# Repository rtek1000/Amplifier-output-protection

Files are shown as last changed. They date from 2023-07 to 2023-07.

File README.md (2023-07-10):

# Amplifier-output-protection
Thermal protection for class AB amplifier output transistors

- Most class AB amplifiers built with NPN and PNP transistors are very poor in protection.
- - Some designs put a simple current limiter, but this does not guarantee the thermal protection of the transistor.
- - Some amplifier manufacturers use a fixed mechanical thermostat of about 100°C against the heatsink.

The partial scheme of an amplifier can be seen below,
- Where there is the current limiting transistor (T10),
- The resistor 0R33 (R37) serves as a reference to monitor the current of the output transistor (T16).
- The other output transistors (T18, T20) are not monitored.
- In this type of circuit, all transistors are expected to have a similar current gain.

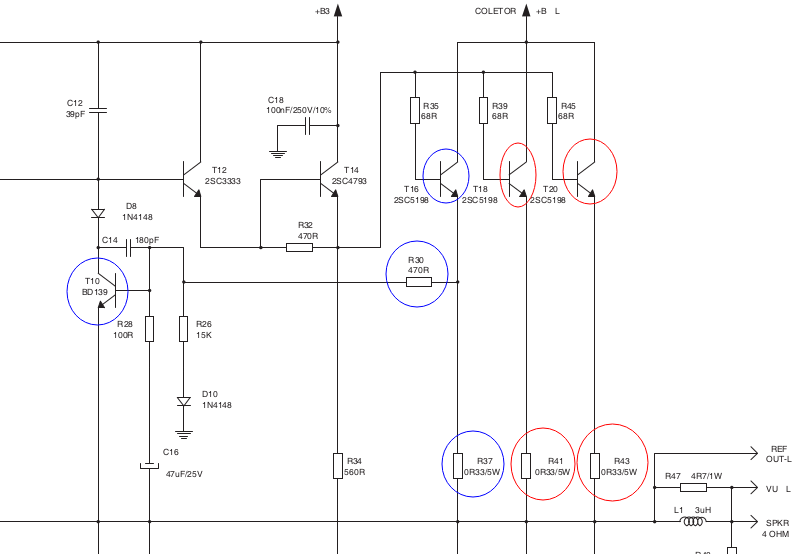
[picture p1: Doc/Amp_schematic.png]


------

The circuit of Thermal protection is based on the TL431 which is widely used in switching power supplies, this IC is very reliable:
- Each output transistor must have a 10k B3950 NTC sensor.
- The relay output can be used to jumper the signal input of amplifier.

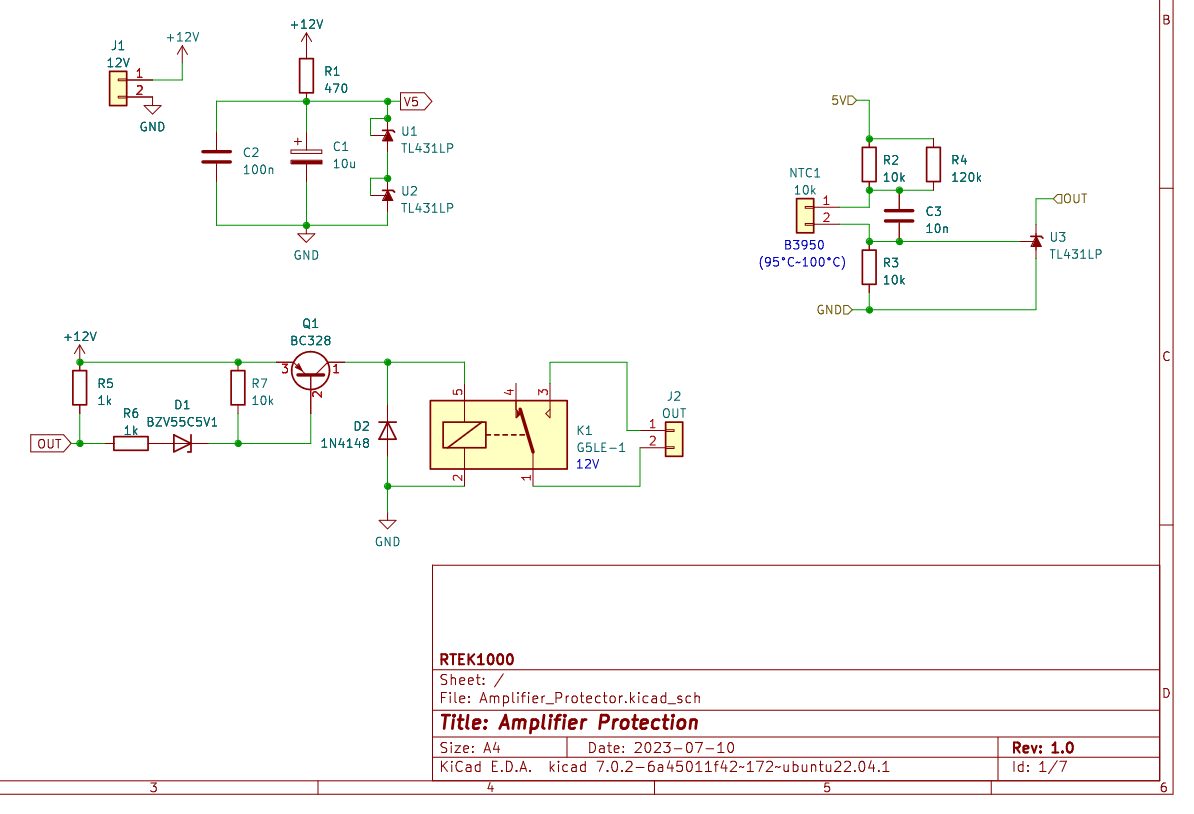
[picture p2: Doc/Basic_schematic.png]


The main schematic shows several blocks "NTC_sensor" so that each transistor can be monitored independently:
- If the amplifier has 20 output transistors, 20 blocks are needed.

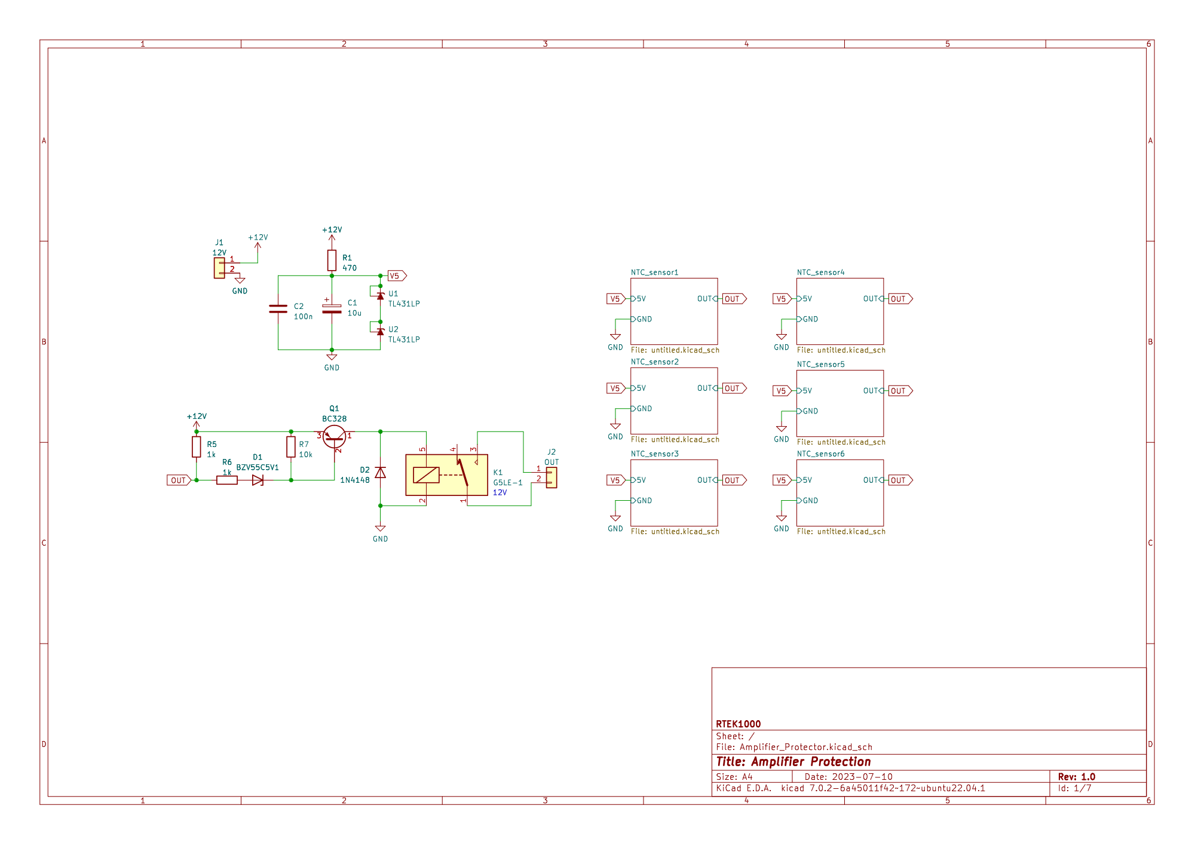
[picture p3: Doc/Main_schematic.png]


To fix the NTC on the transistor, STARS-922 thermal glue can be used.

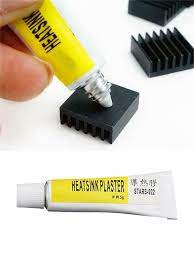
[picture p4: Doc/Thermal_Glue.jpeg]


## Licence:
- Hardware:

Released under CERN OHL 1.2: https://ohwr.org/cernohl

- This library is distributed in the hope that it will be useful, but WITHOUT ANY WARRANTY; without even the implied warranty of MERCHANTABILITY or FITNESS FOR A PARTICULAR PURPOSE.

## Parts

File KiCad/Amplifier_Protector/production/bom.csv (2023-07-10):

Designator | Footprint | Quantity | Value | LCSC Part #
C1 | CP_Radial_D5.0mm_P2.50mm | 1 | 10u
C2 | C_Disc_D5.0mm_W2.5mm_P5.00mm | 1 | 100n
C3, C4, C5, C6, C7, C8 | C_Disc_D5.0mm_W2.5mm_P5.00mm | 6 | 10n
D1 | D_A-405_P2.54mm_Vertical_KathodeUp | 1 | BZV55C5V1
D2 | D_A-405_P2.54mm_Vertical_KathodeUp | 1 | 1N4148
J1 | PinSocket_1x02_P2.54mm_Vertical | 1 | 12V
J2 | PinSocket_1x02_P2.54mm_Vertical | 1 | OUT
K1 | Relay_SPDT_Omron-G5LE-1 | 1 | G5LE-1
NTC1, NTC2, NTC3, NTC4, NTC5, NTC6 | PinSocket_1x02_P2.54mm_Vertical | 6 | 10k
Q1 | TO-92_Inline | 1 | BC328
R1 | R_Axial_DIN0207_L6.3mm_D2.5mm_P2.54mm_Vertical | 1 | 470
R10, R13, R16, R19, R22, R4 | R_Axial_DIN0207_L6.3mm_D2.5mm_P2.54mm_Vertical | 6 | 120k
R11, R12, R14, R15, R17, R18, R2, R20, R21, R3, R7, R8, R9 | R_Axial_DIN0207_L6.3mm_D2.5mm_P2.54mm_Vertical | 13 | 10k
R5, R6 | R_Axial_DIN0207_L6.3mm_D2.5mm_P2.54mm_Vertical | 2 | 1k
U1, U2, U3, U4, U5, U6, U7, U8 | TO-92_Inline | 8 | TL431LP

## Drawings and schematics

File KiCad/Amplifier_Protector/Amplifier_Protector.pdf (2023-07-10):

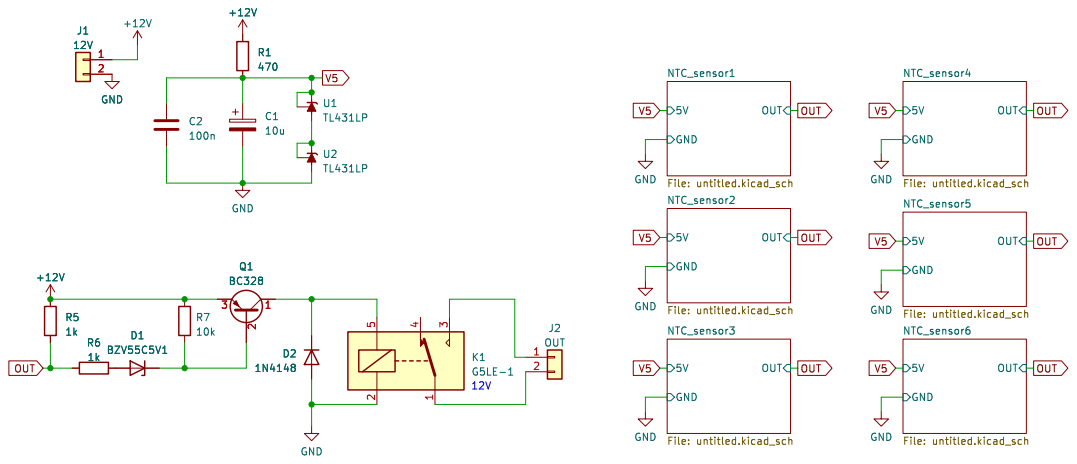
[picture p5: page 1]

Id: 1/7 Title: Amplifier Protection

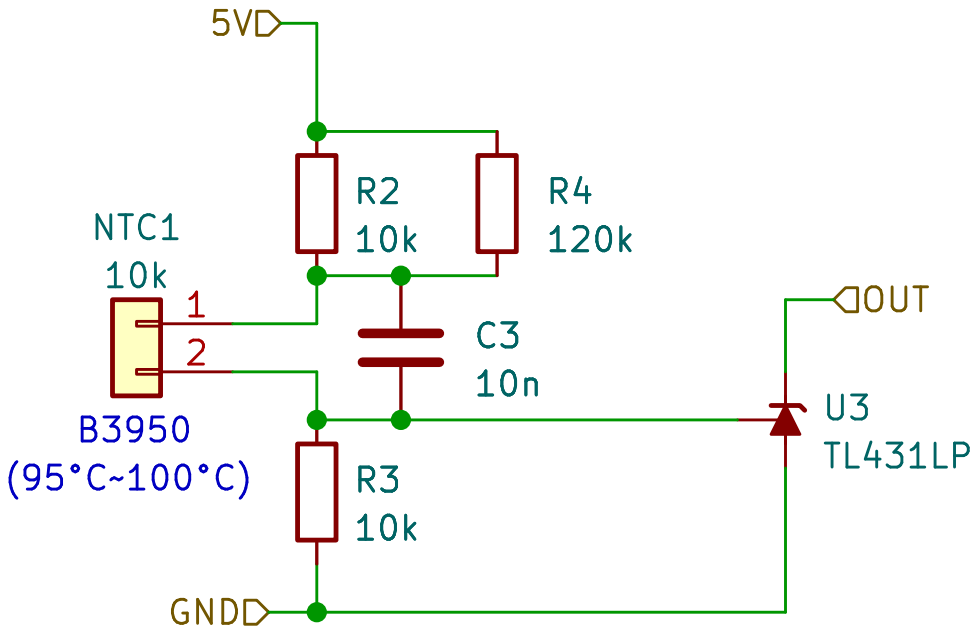
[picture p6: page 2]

Id: 2/7 Title: File: untitled.kicad_sch Sheet: /NTC_sensor1/

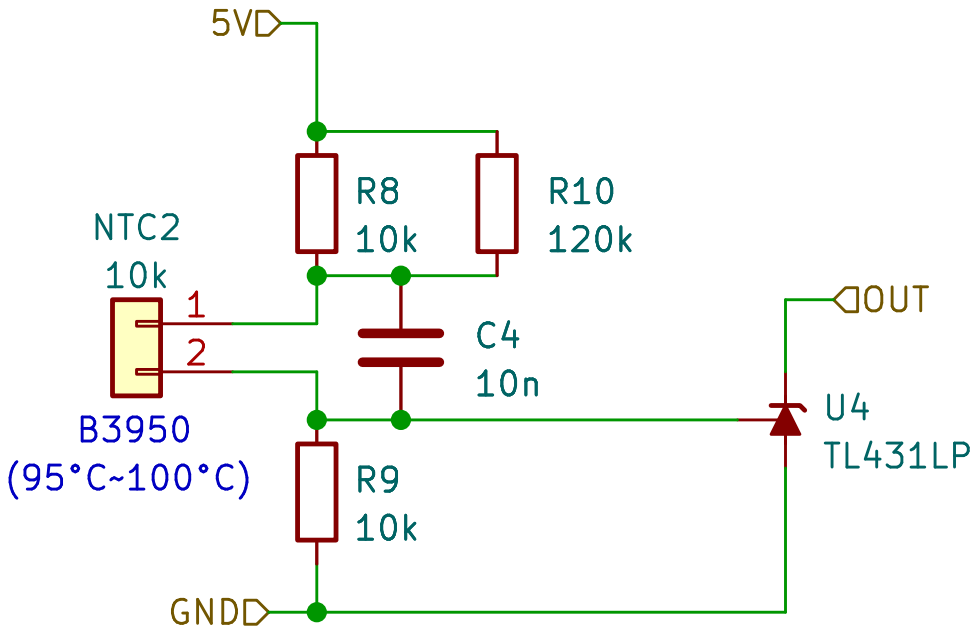
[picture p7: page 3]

Id: 3/7 Title: File: untitled.kicad_sch Sheet: /NTC_sensor2/

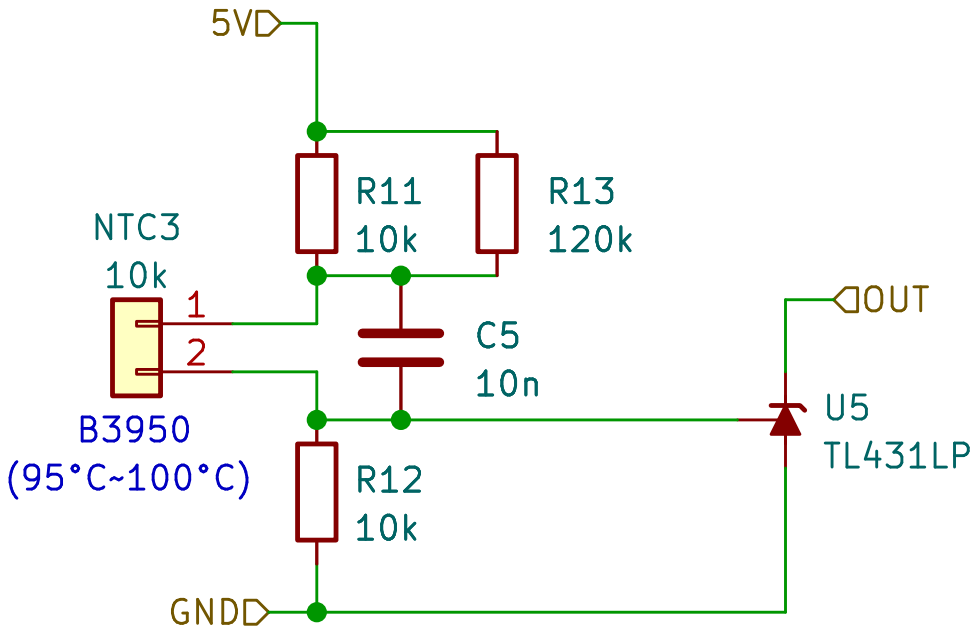
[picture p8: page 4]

Id: 4/7 Title: File: untitled.kicad_sch Sheet: /NTC_sensor3/

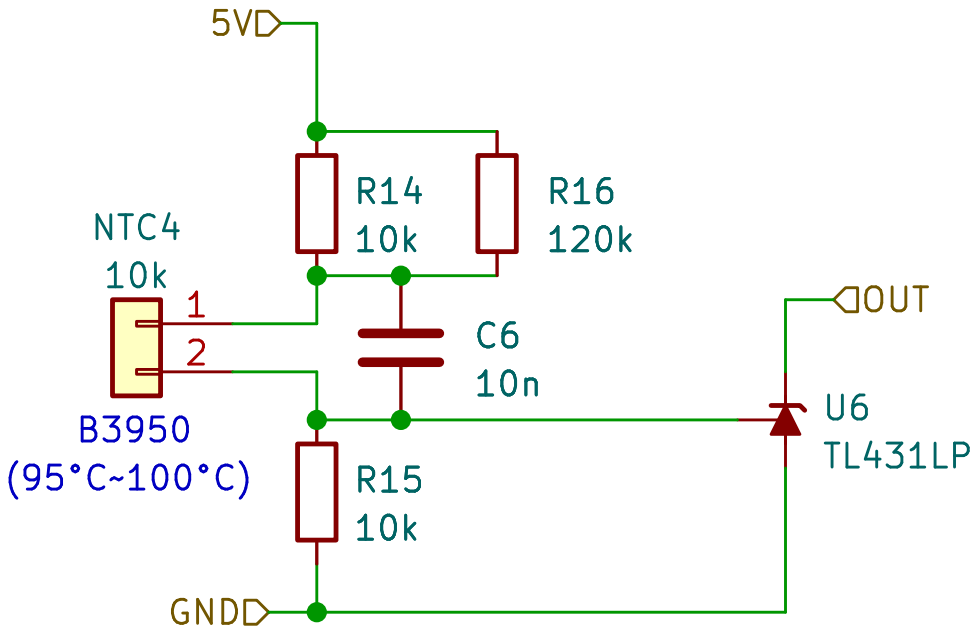
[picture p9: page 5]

Id: 5/7 Title: File: untitled.kicad_sch Sheet: /NTC_sensor4/

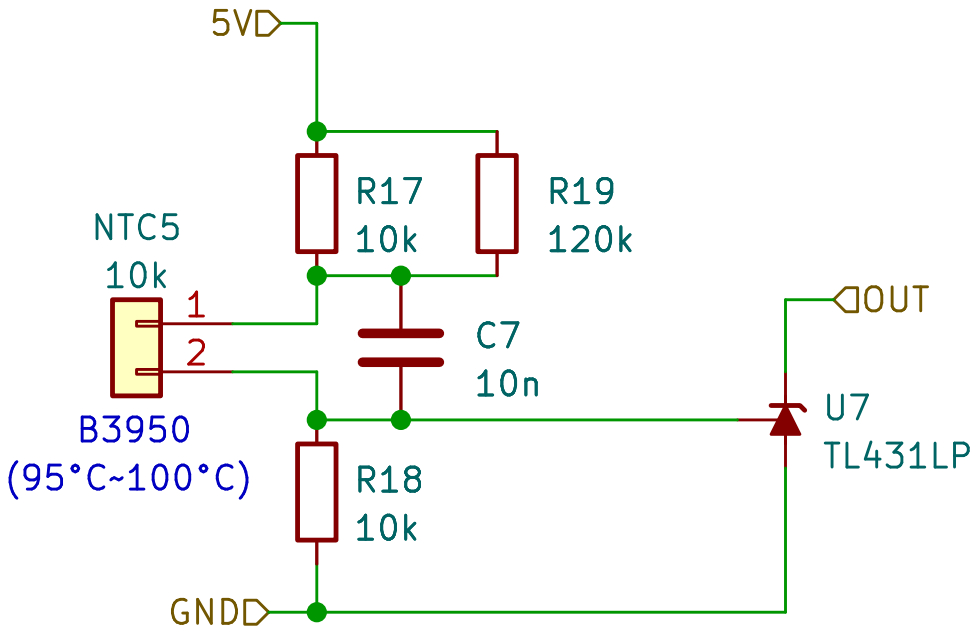
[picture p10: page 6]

Id: 6/7 Title: File: untitled.kicad_sch Sheet: /NTC_sensor5/

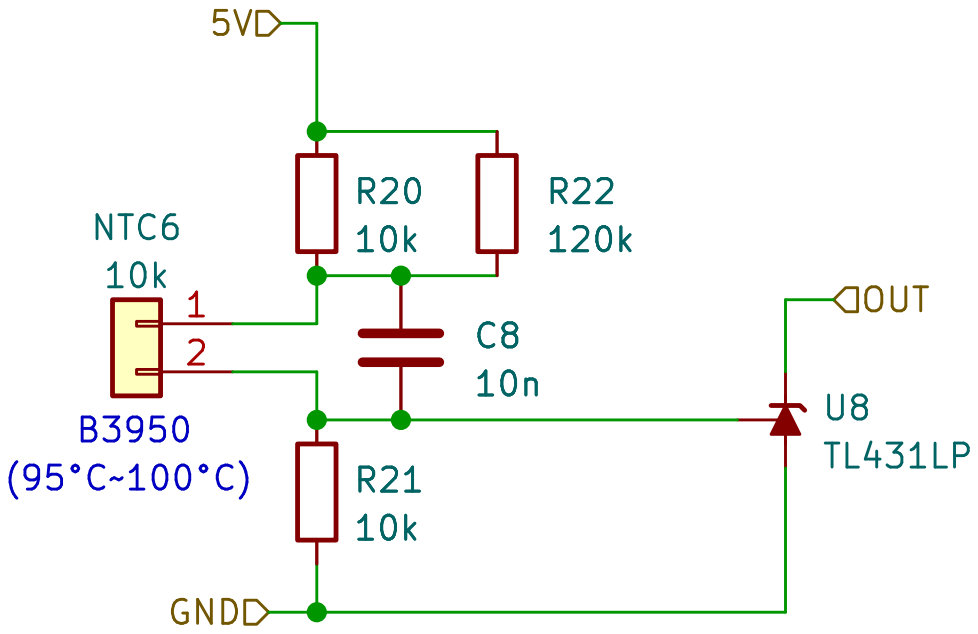
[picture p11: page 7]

Id: 7/7 Title: File: untitled.kicad_sch Sheet: /NTC_sensor6/

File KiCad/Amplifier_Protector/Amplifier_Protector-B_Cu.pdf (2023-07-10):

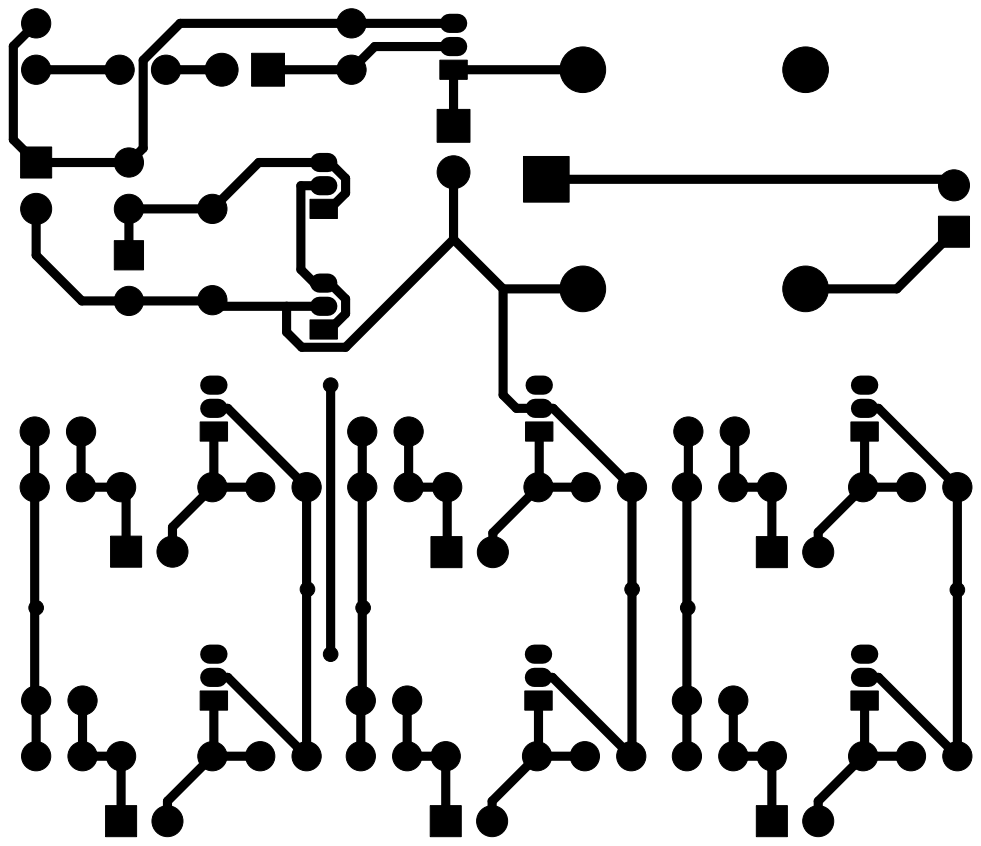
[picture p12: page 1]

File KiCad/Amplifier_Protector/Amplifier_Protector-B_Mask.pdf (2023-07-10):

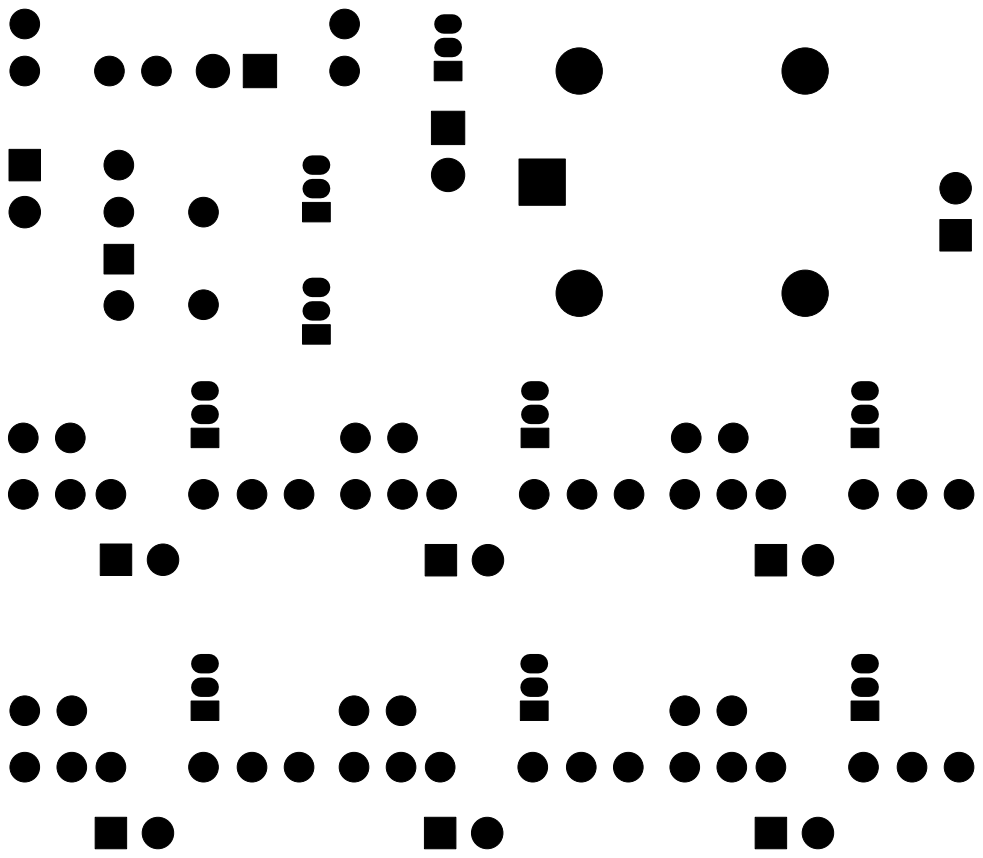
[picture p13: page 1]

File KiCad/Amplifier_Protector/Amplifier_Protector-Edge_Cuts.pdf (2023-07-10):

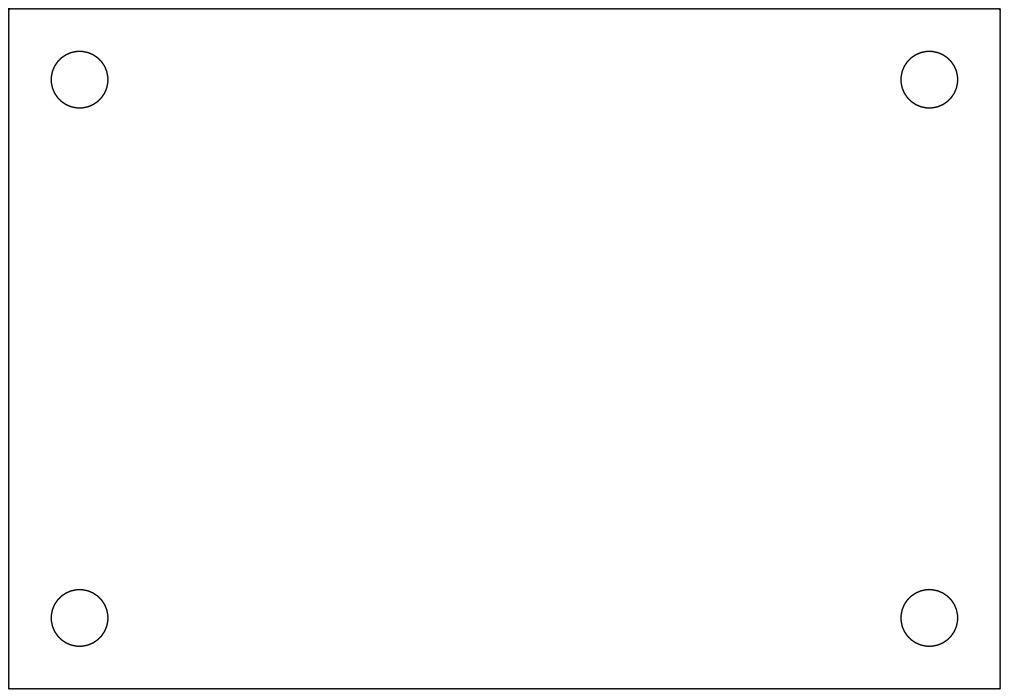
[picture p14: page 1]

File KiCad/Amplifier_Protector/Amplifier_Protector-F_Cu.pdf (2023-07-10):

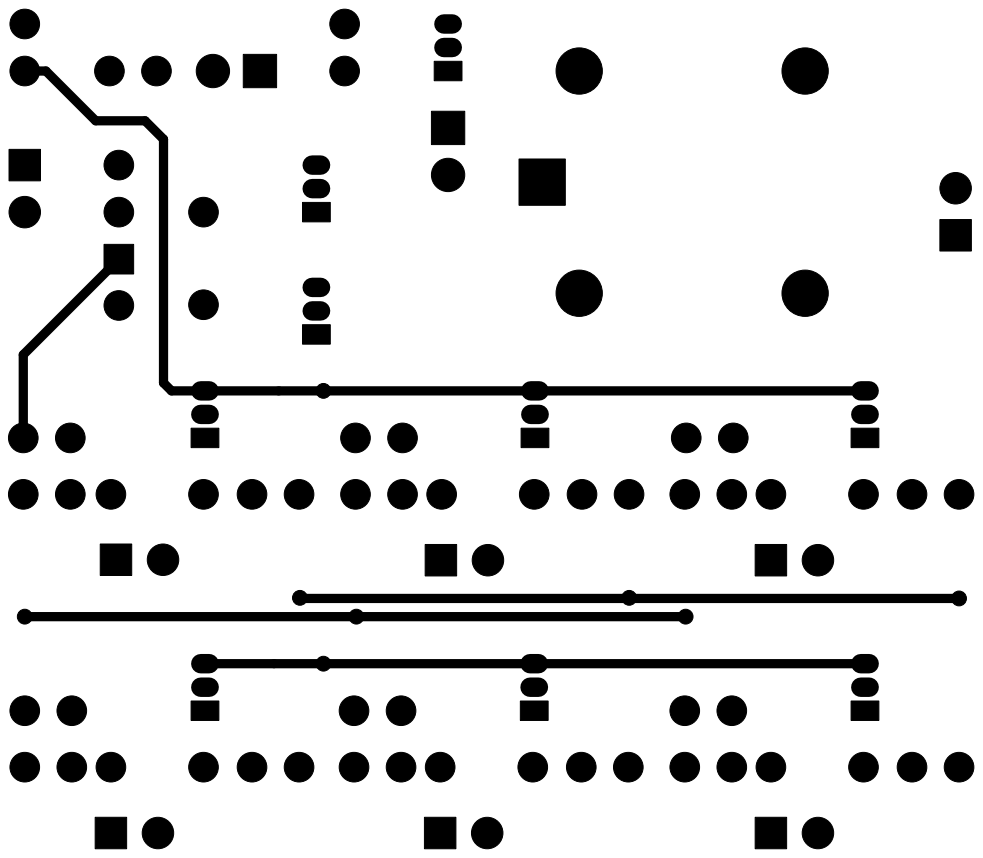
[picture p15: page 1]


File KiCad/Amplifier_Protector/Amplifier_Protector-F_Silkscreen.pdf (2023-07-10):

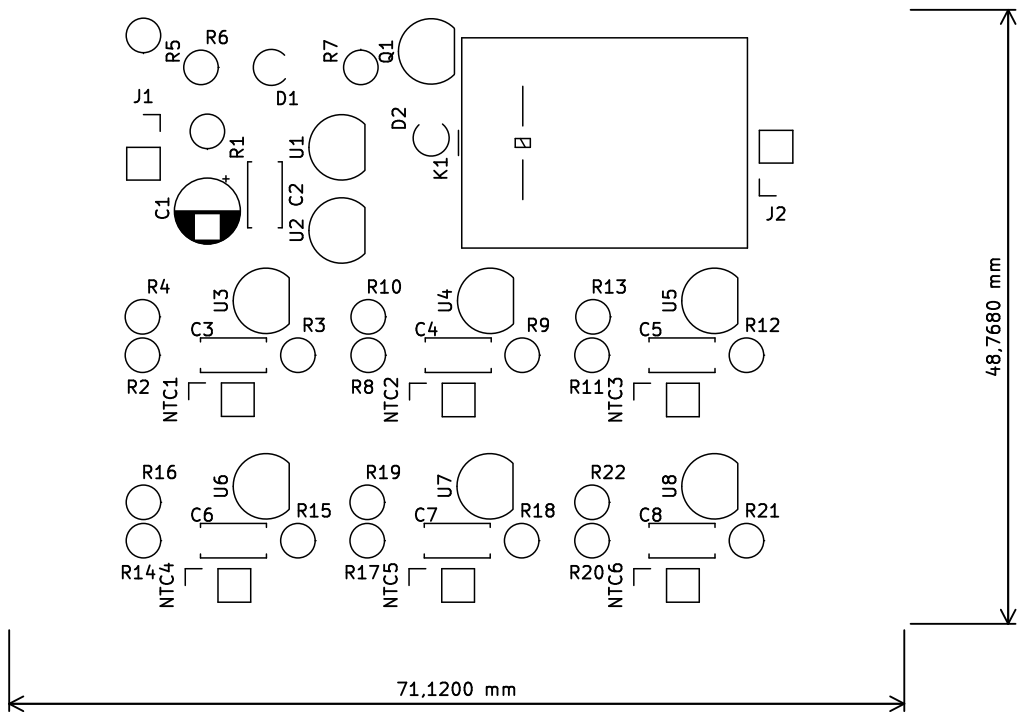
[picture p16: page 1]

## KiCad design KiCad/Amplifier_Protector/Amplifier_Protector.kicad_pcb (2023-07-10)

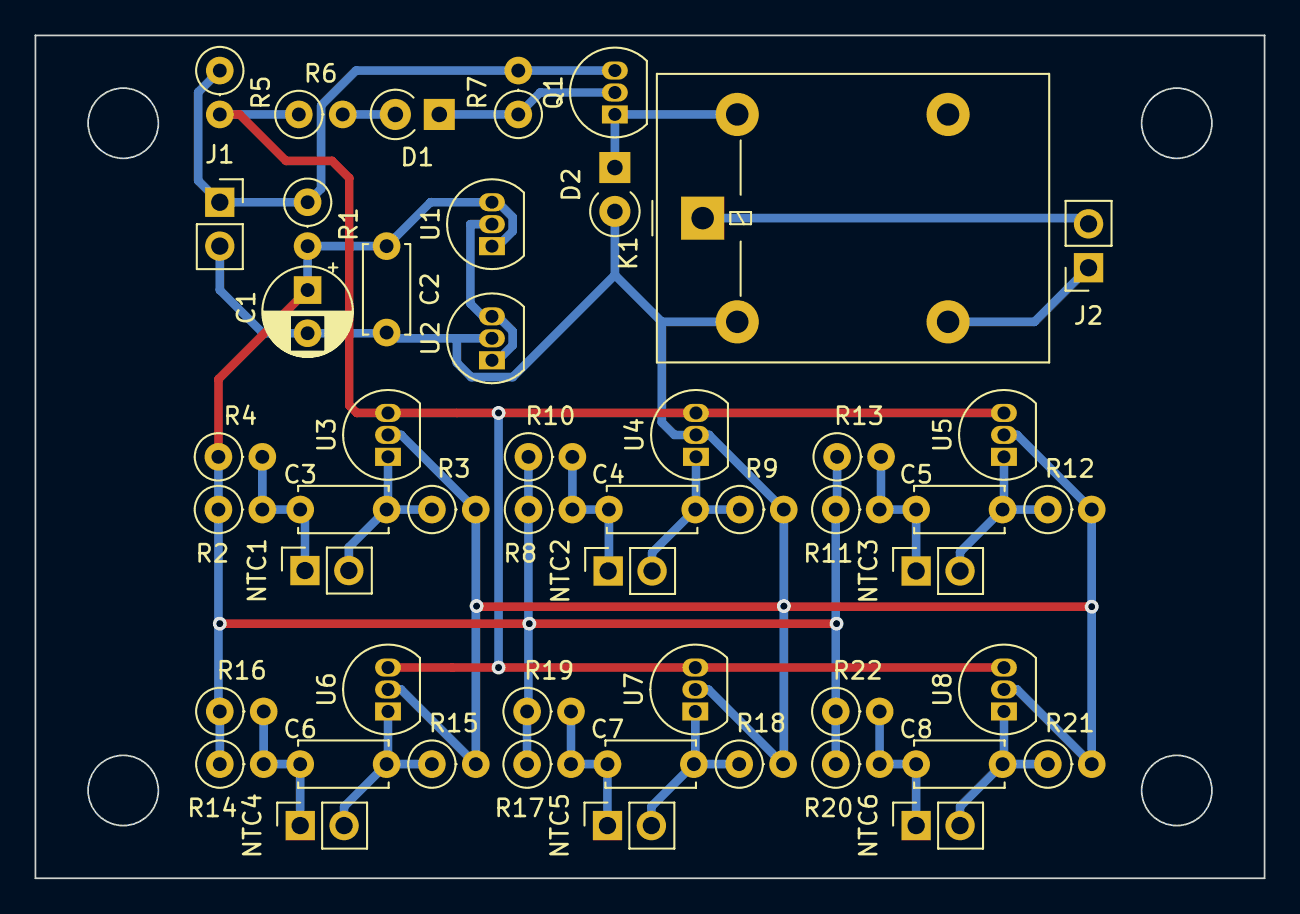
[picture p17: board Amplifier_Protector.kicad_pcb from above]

Board: 2 copper layers, 71.1 x 48.8 mm, 50 parts (0 on the bottom side), 22 nets.

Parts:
C1: 10u; CP_Radial_D5.0mm_P2.50mm
C2: 100n; C_Disc_D5.0mm_W2.5mm_P5.00mm
C3, C4, C5, C6, C7, C8: 10n; C_Disc_D5.0mm_W2.5mm_P5.00mm
D1: BZV55C5V1; D_A-405_P2.54mm_Vertical_KathodeUp
D2: 1N4148; D_A-405_P2.54mm_Vertical_KathodeUp
J1: 12V; PinSocket_1x02_P2.54mm_Vertical
J2: OUT; PinSocket_1x02_P2.54mm_Vertical
K1: G5LE-1; Relay_SPDT_Omron-G5LE-1
NTC1, NTC2, NTC3, NTC4, NTC5, NTC6: 10k; PinSocket_1x02_P2.54mm_Vertical
Q1: BC328; TO-92_Inline
R1: 470; R_Axial_DIN0207_L6.3mm_D2.5mm_P2.54mm_Vertical
R2, R3, R7, R8, R9, R11, R12, R14, R15, R17, R18, R20, R21: 10k; R_Axial_DIN0207_L6.3mm_D2.5mm_P2.54mm_Vertical
R4, R10, R13, R16, R19, R22: 120k; R_Axial_DIN0207_L6.3mm_D2.5mm_P2.54mm_Vertical
R5, R6: 1k; R_Axial_DIN0207_L6.3mm_D2.5mm_P2.54mm_Vertical
U1, U2, U3, U4, U5, U6, U7, U8: TL431LP; TO-92_Inline

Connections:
+12V: J1.1, Q1.3 (E), R1.1, R5.1, R7.2
GND: C1.2, C2.2, D2.2 (A), J1.2, K1.2, R3.2, R9.2, R12.2, R15.2, R18.2, R21.2, U2.2 (A), U3.2 (A), U4.2 (A), U5.2 (A), U6.2 (A), U7.2 (A), U8.2 (A)
unnamed: D1.2 (A), R6.2
unnamed: D1.1 (K), Q1.2 (B), R7.1
unnamed: D2.1 (K), K1.5, Q1.1 (C)
unnamed: J2.1, K1.3
unnamed: J2.2, K1.1
unnamed: C3.1, NTC1.1, R2.2, R4.2
unnamed: C3.2, NTC1.2, R3.1, U3.1 (REF)
unnamed: C4.1, NTC2.1, R8.2, R10.2
unnamed: C4.2, NTC2.2, R9.1, U4.1 (REF)
unnamed: C5.1, NTC3.1, R11.2, R13.2
unnamed: C5.2, NTC3.2, R12.1, U5.1 (REF)
unnamed: C6.1, NTC4.1, R14.2, R16.2
unnamed: C6.2, NTC4.2, R15.1, U6.1 (REF)
unnamed: C7.1, NTC5.1, R17.2, R19.2
unnamed: C7.2, NTC5.2, R18.1, U7.1 (REF)
unnamed: C8.1, NTC6.1, R20.2, R22.2
unnamed: C8.2, NTC6.2, R21.1, U8.1 (REF)
unnamed: U1.2 (A), U2.1 (REF), U2.3 (K)
OUT: R5.2, R6.1, U3.3 (K), U4.3 (K), U5.3 (K), U6.3 (K), U7.3 (K), U8.3 (K)
V5: C1.1, C2.1, R1.2, R2.1, R4.1, R8.1, R10.1, R11.1, R13.1, R14.1, R16.1, R17.1, R19.1, R20.1, R22.1, U1.1 (REF), U1.3 (K)
